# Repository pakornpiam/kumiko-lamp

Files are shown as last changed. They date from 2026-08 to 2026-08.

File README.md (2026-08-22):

# Kumiko Lamp — parametric, print-ready STL set

A parametric lantern for an E27 or E14 LED bulb, available in two styles. **Classic** is
the original square four-panel lamp; **Modern** is a two-part cylindrical lamp with a
threaded patterned shade. Classic remains the default, and its geometry and stock STLs are
unchanged.

The Classic parts print with **no supports** and assemble with sliding
mortise-and-groove joints — no glue and, as it ships, no fasteners of any kind. Four M3
screws are an option, not a requirement; see *Screwing the Classic cap down*. The stock
Classic is **190 × 190 × 236 mm** on its four legs. The stock Modern pairs a
**Ø100 shade and Ø100 base** at 298 mm assembled height. Both are designed for the
256 mm bed of the A1 / P1S / X1C.

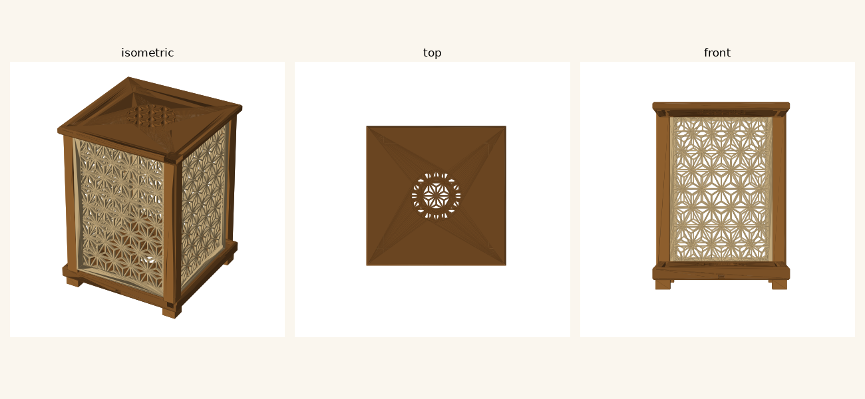
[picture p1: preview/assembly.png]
assembled Classic lamp


## Two ways to build it

**[`web/index.html`](web/index.html) — the configurator.** Open it in a browser, choose
**Classic** or **Modern** under *Lantern*, adjust the dimensions, pattern, joints and
lamp-holder sizing, turn the lamp in 3D, and download the STLs individually or as a zip.
Each style remembers its own settings while you switch between them. No install, no
network, one self-contained file. It re-solves the joinery live and refuses to export a
lamp that will not go together. The new controls and messages are available in both
English and Thai.

**`kumiko_lamp.py` — the generator.** Same selected style, same numbers, built with real
CSG so every part is a strictly manifold shell. Use this if your slicer is fussy, or for
the pre-generated set in `stl/`.

The two agree: for identical settings the structural parts, adapter ring and downloaded
Modern shade come out of the browser watertight and closely volume-matched to the Python
parts. Classic's live-built lattices use a lighter representation — see
[Manifold-ness](#manifold-ness) below.

## Lantern styles

**Classic** is the existing square lamp: four interchangeable panels slide between four
posts, with separate feet, a grooved base and a removable top cap. It supports all thirteen
offered patterns, optional diffusers, two-piece posts, cap screws, finials and reusable
snap locks.

**Modern** is a hollow cylindrical base and a removable cylindrical shade. The reference
preset uses a 100 mm shade diameter, a 100 mm base diameter, a 218 mm shade and a 90 mm
base. In the configurator, **Shade diameter** and **Base diameter** begin linked: moving
the shade-diameter control moves both until you edit Base diameter directly. That first
base edit unlinks them, allowing a broader body while later shade changes keep
the chosen base size. Set Base diameter equal to Shade diameter to relink them; this link
state is remembered when you switch between Classic and Modern. The shade overlaps the
base's threaded neck by 10 mm, producing the 298 mm assembled height. Its upper and lower
rings are each 10 mm high, with the selected Kumiko lattice wrapped continuously around the
cylinder between them. The base carries the male thread and the shade's lower ring carries
the matching female thread. The threaded neck follows the shade diameter; the base body
uses its independently selected diameter. Immediately below the neck, the body contracts
through a 45-degree transition; after the base is inverted for printing, that transition
expands without a horizontal cantilever.

Modern supports the thirteen Kumiko patterns only. The three Lai Thai compositions are
panel-sized artwork and cannot be wrapped periodically, so Modern rejects them instead of
substituting another design. For softer light, set **Diffuser thickness** above zero to
generate a removable closed-top cup, or leave it at zero and add a paper or vellum
liner.

Modern **Seigaiha** is the exception to the normal swept-slat construction. It preserves
the four signed contours from `reference/seigaiha-blue.svg` as a filled 2 × grid by
1 × grid repeat: coloured regions print and white regions remain light openings. At the
reference 1.6 mm material setting it matches the source; Material width offsets that
region thinner or thicker. A fit guard rejects any rounded opening whose estimated roof
bridge exceeds 9 mm, and the repeat-boundary tips are normalized so every row welds.
Classic Seigaiha remains the original three-arc line pattern.

**Sakura V2** is also filled source artwork. Its repeat is extracted directly from
`reference/vectorstock_20834246.svg`: all 79 signed contours preserve the interlocking
blossoms, their openings, and the varying member widths. Pattern pitch scales the complete
repeat; Material width is intentionally ignored for this motif because a uniform offset
would alter the artwork and disconnect its finest joints.

---

## Print list

### Classic (default)

| STL | Qty | Size (mm) | Orientation on the plate |
|---|---|---|---|
| `panel_asanoha.stl` | **4** | 155.7 × 210 × 4 | Flat, **lattice face down**. As exported — drop it on the plate. |
| `post.stl` | **4** | 18 × 18 × 210 | Standing upright, as exported. Use a brim. |
| `base.stl` | **1** | 190 × 190 × 16 | Flat, as exported. Underside is dead flat. |
| `top_cap.stl` | **1** | 190 × 190 × 10 | Flat, as exported — **already flipped** into print orientation. |
| `leg.stl` | **4** | 20 × 20 × 20 | Standing on its foot, as exported. Tenon points up. |
| `socket_adapter_ring.stl` | **1** | Ø49.6 × 4 | Flat. See *E27 / E14 holder* below. |
| `diffuser_plate.stl` | 0 or **4** | 155.7 × 210 × 1.2 | Flat, as exported. Only if you want a printed diffuser — see *Classic diffuser* below. |
| `finial.stl` | 0 or **4** | 20 × 20 × 10 | Screw-head finial cap, standing on its head. Skirt points up. Only with the cap screws. |

Swap in `panel_kikkou.stl`, `panel_mitsukude.stl`, `panel_kawari_asanoha.stl`,
`panel_kagome.stl`, `panel_masu.stl`, `panel_masu_tsunagi.stl`, `panel_senbon.stl`,
`panel_goma_gara.stl`,
`panel_bishamon_kikkou.stl`, `panel_seigaiha.stl`, `panel_sakura.stl` or
`panel_sakura_v2.stl` for a different motif — all thirteen Classic panels are dimensionally identical
and interchangeable. Roughly in order of open area: masu and kikkou are
the airiest, asanoha and goma-gara the densest.

### Modern

| STL | Qty | Reference size | Orientation on the plate |
|---|---|---|---|
| `modern_shade_asanoha.stl` | **1** | Ø100 × 218 mm | Upright, as exported. Use a brim if your slicer or material needs it. |
| `diffuser_plate.stl` | 0 or **1** | Ø91.2 × 208 × 1.2 mm wall/lid | **Lid down, as exported.** Optional removable Modern diffuser cup. |
| `modern_base.stl` | **1** | Ø100 × 90 mm nominal | **Inverted, as exported.** The mounting deck starts on the bed and the neck reaches the body through a 45-degree transition. |
| `socket_adapter_ring.stl` | **1** | Ø49.6 × 4 mm | Flat. The same E27/E14 adapter used by Classic. |

Replace `asanoha` in the shade filename with `kikkou`, `mitsukude`, `kawari_asanoha`,
`kagome`, `masu`, `masu_tsunagi`, `senbon`, `goma_gara`, `bishamon_kikkou`, `seigaiha`,
`sakura` or `sakura_v2`. A reference-size `modern_base.stl` and all thirteen
`modern_shade_<pattern>.stl` files are checked into `stl/`; custom sizes are generated or
downloaded on demand. The supplied reference STLs used to establish the proportions are
not copied into the repository.
The configurator's part table, individual filenames, ZIP name and ZIP contents follow the
selected style; a Modern download does not include Classic-only parts. Individual filenames
stay stable at `modern_base.stl`, `modern_shade_<pattern>.stl` and
`socket_adapter_ring.stl`. A linked Ø100 pair downloads as
`kumiko-lamp-modern-100mm-<pattern>.zip`; unequal diameters are explicit in names such as
`kumiko-lamp-modern-shade100mm-base140mm-<pattern>.zip`.

**Seigaiha** (青海波, "blue sea wave") is the odd one among the kumiko: a field of curves
rather than a straight lattice. Classic uses rows of overlapping three-arc fans, each row
offset half a fan from the one below. Modern instead uses the imported filled repeat
described above, with its wave ends joined for one support-free cylindrical shell.

**Sakura** (桜, "cherry blossom") starts with the same equilateral-triangle groundwork
as other straight-slat Kumiko. A three-spoke insert runs from each triangle's centre to
its edge midpoints, turning the repeating openings into geometric petals. It uses the same
adjustable pitch and material width in Classic and Modern, and the Classic cap keeps the
Sakura lattice rather than substituting a fallback grille.

**Sakura V2** is the exact filled repeat supplied in
`reference/vectorstock_20834246.svg`, not a rotation of the straight-slat Sakura pattern.
It preserves the source's interlocking floral silhouette and varying stroke weights in
Classic and around the Modern shade. Its dense contours are unsuitable at cap scale, so
the Classic top vent safely uses the Kikkou grille when Sakura V2 is selected.

**Masu** (枡格子) and **Senbon** (千本格子) are the plain ones: a bare square grid, and
close-set vertical bars crossed by a rail every third bar. Senbon's bars run at a third of
the pattern pitch, so the stock 28 mm gives a 9.3 mm spacing — fine enough to earn the
"thousand sticks" of its name. At 12 and 22 slats they are the two cheapest panels to
print, and Masu is the most open of the thirteen.

## The Lai Thai family is currently disabled

Three Thai compositions — **Kranok Kan Khot**, **Dok Phut Tan** and **Thai Rosette** — are
still in the repo and still build, but are **not offered**: they are absent from the
configurator's pattern picker, from `--pattern`, and from `--all`. Their three
`panel_*.stl` files and preview SVGs remain checked in, and stop being regenerated.

To bring them back, set **both** flags to true and regenerate:

```
kumiko_lamp.py   LAITHAI_ENABLED = True
web/index.html   var LAITHAI_ENABLED = true;
```

They are switched off rather than deleted because Thai Rosette remains a complete imported
region implementation and test case. The same region machinery now also carries Sakura V2.
The descriptions below are kept for that reason.

**Kranok Kan Khot**
(กระหนกก้านขด) is a different kind of thing: not a repeating lattice but **one composition filling the
whole panel** — a diamond medallion of Thai flame work, with a column of nested pointed
lenses on the axis, a spike to the apex, and volutes at the waist throwing flames out along
the diamond's edges. It is bilaterally symmetric, so only the right half is authored and
mirrored. All four panels carry the same artwork.

Two consequences worth knowing. Because there is no tile, `--grid` has no pitch to set for
this pattern and drives curve tessellation instead. And the top cap keeps a kumiko grille
when it is selected: scaled into the 70 mm vent the composition is just a shrunken copy of
the panel, ~19k triangles in a hole you can barely see into.

**Dok Phut Tan** (ดอกพุดตาน) is a broad, layered flower derived from the peony-like motif
used in early-Rattanakosin Thai ornament. Three scalloped petal tiers grow from a common
heart, while four scrolling stems, paired leaves and forked perimeter braces tie it into
the side, top and bottom rails. Like Kranok,
it is one panel-sized composition rather than a repeating tile, and the cap uses the
Kikkou fallback grille.

**Thai Rosette** is different again: it is not drawn in code at all but **imported**
from `reference/laithai.svg`. Where every other pattern is line work swept into
fixed 1.6 mm slats, this one is a *filled region* — an outer contour plus 13 holes —
so its stroke thickness varies the way the original artwork does. It is fitted to the
panel width undistorted, which leaves a plain band top and bottom, and a thin border
with four diagonal ties and four centre spokes holds it together: on its own the
artwork is two loose pieces and neither reaches the frame.

To change it, edit the SVG and re-run `python tools/svg2pattern.py reference/laithai.svg`,
then paste the table into both implementations — the browser core has no file access,
so the contours have to be baked in.

`post_lower.stl` + `post_upper.stl` are an **optional** two-piece post joined by an 8 mm
pin (117 mm and 105 mm tall). Use them only if you would rather not print a 210 mm tall
slender tower, or you are on a 180 mm-Z machine. Print 4 of each *instead of* `post.stl`.

`assembly_preview.stl` is **not for printing** — a generator run writes the selected style
with its print parts placed upright for checking fit in a viewer. The checked-in stock
preview remains Classic; generate Modern into a separate `--out` directory when you want
its preview.

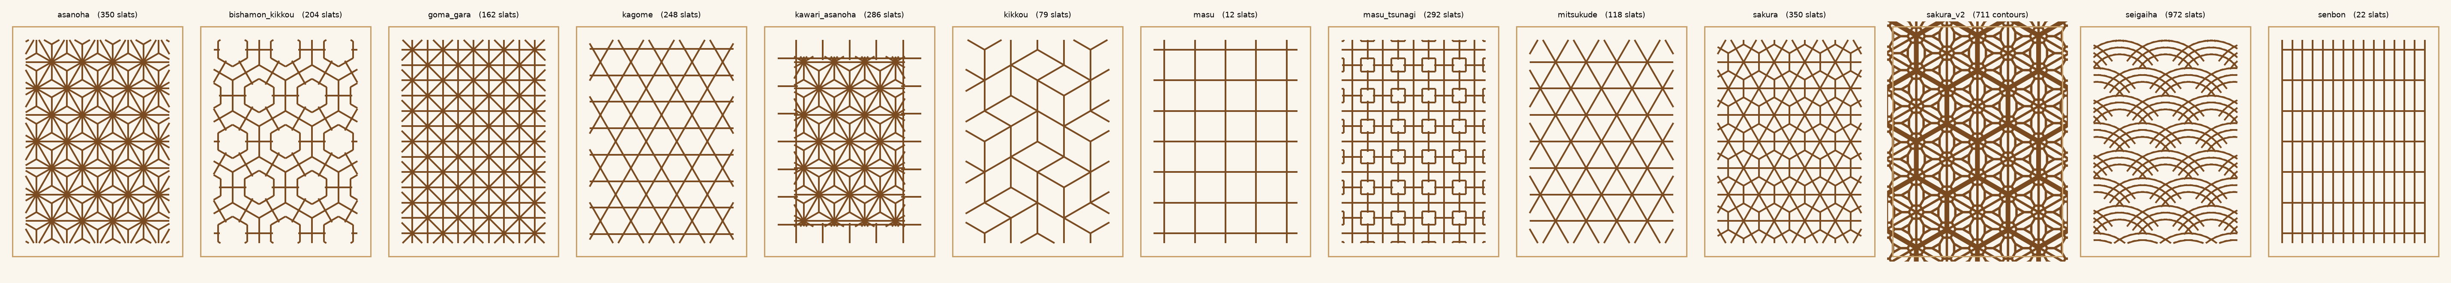
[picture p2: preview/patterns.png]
patterns


## Slicer settings (Bambu Studio)

These are a safe starting point for either style; keep the exported orientations listed
above.

| | |
|---|---|
| Nozzle / layer | 0.4 mm / 0.2 mm — use 0.16 mm on the panels for a crisper lattice |
| Wall loops | **4** — slats are 1.6 mm wide, exactly 4 × 0.4, so they come out fully solid with no infill inside them |
| Infill | 15 % gyroid (only solid frames, posts, bases and the Classic cap ever see it) |
| Supports | **Off** for every part |
| Brim | 5 mm on the posts and panels; optional elsewhere |

Rough Classic filament: one full set is 1323 cm³ of solid volume (1641 g if it were
100 % dense).
The panels and posts are effectively solid; the base and cap are slabs that infill
hollows out considerably. At 15 % infill expect very roughly **700–800 g** — your
slicer's estimate is the one to trust.

## Assembly

### Classic

1. Press the four **legs** into the blind sockets in the underside of the **base**.
2. Drop the four **posts** into the corner sockets on top of the base.
3. Slide each **panel** down between two posts — the grooves in the posts catch its
   side edges, and its bottom edge lands in the groove in the base. Lattice faces out.
4. Fit the **top cap** over the four post tops and the four panel top edges.

It is a friction fit throughout, so the cap lifts off to change the bulb. Fit the optional
cap screws and it does not: four finials come off and four screws come out first. Joint
clearances are 0.4 mm on the grooves, 0.3 mm on panel width and 0.35 mm on the leg
tenons. If your printer runs tight and the panels bind, raise `slot_clear` and reprint
the posts — that is the one part you would need to redo.

### Modern

1. Fit the selected E27/E14 holder and `socket_adapter_ring.stl` to the mounting deck,
   route its cord through the bottom outlet, and complete the wiring before fitting the
   shade.
2. Turn `modern_base.stl` upright after printing; it is exported upside-down only to keep
   the mounting deck and male thread support-free.
3. Add an optional paper liner inside the shade, keeping it clear of the bulb and vents.
4. Lower the shade over the base neck and screw it down through the full 10 mm engagement.
   Stop when the full engagement is reached; do not force or overtighten the printed thread.

Unscrew the shade to change the bulb. The thread uses a 2 mm pitch, 0.8 mm radial depth and
45° printable flanks. Its **radial** clearance slider spans 0.10 to 0.80 mm; the default
0.30 mm is a starting point, not a universal fit:

```bash
python3 kumiko_lamp.py --style modern --thread-clearance 0.20  # tighter
python3 kumiko_lamp.py --style modern --thread-clearance 0.30  # default
python3 kumiko_lamp.py --style modern --thread-clearance 0.60  # looser
```

Start at 0.30 mm, then tune for the material, layer height and dimensional accuracy of your
printer. The generator rejects settings that leave unsafe thread walls or mounting-deck
thickness. A wider independent base does not change the thread fit: its neck still matches
the shade, while the lower body and its support-free 45° transition expand to the selected
base diameter. Check that diameter against both printer-bed axes.

## Classic legs

The legs are separate parts rather than moulded onto the base, and that is deliberate:
hung off the underside they would turn the whole 190 mm slab into an unsupported ceiling,
and every part here prints without supports. A 10 mm square tenon plugs into a blind
socket under each corner post, so the load runs straight down post → base → leg. Square
rather than a round pin, so a leg cannot rotate out of line with the base edges.

They also lift the base 12 mm off the table, which gives the cord somewhere to go.

### Reusable snap locks

The feet are a clearance fit by default. Add a light reusable snap detent with:

```bash
python3 kumiko_lamp.py --snap-lock       # recommended 0.2 mm engagement
python3 kumiko_lamp.py --snap-lock 0.1   # lighter fit
python3 kumiko_lamp.py --snap-lock 0     # off (the default)
```

The same setting applies to the four feet and the four screw-head finial caps, so a
screwed lamp has all eight matching corner pieces retained. Two small tabs flex into
matching hidden recesses; the feet have a hollow tenon and the finials flex around their
screw cavity. Start at 0.2 mm and tune the **Snap engagement** slider for your printer and
material. PETG is preferred for repeated removal; PLA snaps are more brittle. No snap fit
has been test-printed yet.

## Screwing the Classic cap down

The cap is a friction fit and needs nothing else. If you would rather it could not be
lifted off — a lamp that travels, or one somewhere a cat can reach — each post top can
take a **heat-set threaded insert**, with an M3 screw down through the cap into it and a
finial over each screw to hide the head. The finials echo the four legs: four feet below,
four caps above.

```bash
python3 kumiko_lamp.py --post-insert 4.0    # M3, the working value
python3 kumiko_lamp.py --post-insert 0      # none (the default)
```

In the configurator it is the **Insert hole** slider under *Cap screws*; `0` means none.

**You will need:** 4 × M3 heat-set insert, OD 4.6 × 5.7 mm long (the common
Ruthex/CNC-Kitchen size, 4.0 mm pilot) · 4 × M3 × 8 socket cap screw · a 2.5 mm hex key ·
a soldering iron to set the inserts.

Set the inserts into the post tops before assembly, build as usual, then drop a screw
through each corner of the cap and nip it up — **snug, not tight**. The screw pulls the cap
down until the post bottoms out against it, so there is nothing to gain from more torque
and an insert to strip if you keep going. The finials are a light press fit by default or
a removable detent with `--snap-lock`; leave them unglued or you will never get the bulb
out.

**Ø4.0 is the largest hole an 18 mm post will really take.** The panel grooves reach in to
within 3 mm of the post axis, so a 4 mm hole leaves a 1 mm wall — and that wall is where
the insert's melt wants to bulge, into the groove face. `check_fits` refuses anything past
two extrusions of wall, but if you want M4, widen the post to 20 mm first.

## Classic diffuser

The back of every panel is pocketed 0.6 mm deep, and the pocket runs out through the top
edge. Slide a sheet of **shoji paper or vellum** down into it before you fit the cap.
The pocket holds it on the other three sides; the top is hidden inside the cap groove.
Cut the sheet to **139.7 × 202 mm**. Traditionally this is glued — a little PVA around
the edge is plenty, but friction alone works.

Leave it out entirely if you want hard-edged shadows thrown on the wall instead.

### Or print the diffuser

Instead of paper, each groove can take a **clear printed plate** that sits behind the
lattice — same job, no cutting or gluing, and it will not yellow.

```bash
python3 kumiko_lamp.py --diffuser-plate 1.2     # the working thickness
python3 kumiko_lamp.py --diffuser-plate 0       # none (the default)
```

In the configurator it is the **Diffuser plate** slider under *Panel*; `0` means none.
A glazed side renders translucent so you can see the plate through the lattice.

`diffuser_plate.stl` shares the panel's 155.7 × 210 footprint, so the groove holds it on
all four edges. Print it in **clear PETG or PLA** — 1.2 mm is six layers, and it prints
flat with no supports.

The groove widens to take both, `panel + plate + clearance`, and **that is what caps the
plate at 1.6 mm**: the post's two grooves are notches cut 6 mm deep into an 18 mm post,
and once each is half as wide as the 6 mm they leave, the two meet and the post's corner
falls off. `check_fits` refuses anything that reaches it. Nothing else moves — panel
width, the patterns and every other part are identical glazed or not.

You can still use paper as well; the 0.6 mm rebate is untouched.

### Modern diffuser cup

The same `--diffuser-plate 1.2` option creates one cylindrical cup in Modern mode. It rests
on the lower ring, passes through the upper ring, and finishes level with the shade's top
edge. It sits 0.4 mm radially inside the lattice, so it can be removed through the shade
opening. Its upper end is a completely solid flat lid, its lower end remains open, and the
selected 1–4 mm thickness controls both the wall and the lid. The STL is already turned
**lid-down**: print it that way in
**translucent PETG** so the lid starts on the bed and the cup needs no supports. `0` keeps
the original three-part Modern print set and lets you use paper or vellum instead. Because
the lid reduces upward convection, retain the lamp's LED-only, maximum-9 W requirement.

## E27 / E14 holder

Both styles reuse the same holder presets and stable `socket_adapter_ring.stl` filename.
The Classic base has a Ø40 mm through-bore, a Ø50 × 4 mm counterbore around it, and an
enclosed cord tunnel through one side wall. The Modern base puts the same bore and
counterbore in its circular mounting deck and routes the cord through the bottom outlet.

`socket_adapter_ring.stl` seats in the counterbore and is what your holder clamps
against. The E27 preset keeps the original Ø26.5 mm bore; the E14 preset uses a Ø27 mm
bore for the common threaded-sleeve style:

```bash
python3 kumiko_lamp.py --holder e14
```

E14 and E27 name the bulb interface, not the holder's mounting neck, and actual hardware
varies. For example, [one commercial E14 sleeve is specified at Ø27.5 mm](https://produkte.kopp.eu/en/id/212501049/). Measure yours
and override the preset when needed:

```bash
python3 kumiko_lamp.py --holder e14 --socket-neck 27.5
```

It is a 5 g, few-minute print, which is exactly why the fit lives in a separate part
rather than in either base. Select the same holder preset independently in Classic or
Modern; a subsequent manual neck adjustment keeps the selected E27/E14 identity.
The configurator's CLI echo includes `--holder` and also `--socket-neck` when you move the
neck away from that holder's preset.

## Heat — please read

**LED bulb only, 9 W maximum.** A filament or halogen bulb will soften and deform this
lamp. PLA starts to go at around 60 °C.

Ventilation is built in. Classic has 1640 mm² of open area through the cap grille and a
16-slot ring in the base under the bulb; Modern adapts that vent layout to its circular
mounting deck and vents through the open lattice above. Both are sized for a cool-running
LED and nothing more.

I would **print either base, the Classic top cap and the Modern shade in PETG** — they are
the parts nearest the bulb, and PETG holds up to roughly 80 °C. PLA is fine for the Classic
panels and posts. All-PETG is fine too.

Mains wiring is your responsibility. If you are not confident terminating a lamp holder,
use a ready-made corded E27 or E14 socket rather than making one up.

## Customising

Every dimension lives in the `Params` dataclass at the top of `kumiko_lamp.py`. The ones
worth reaching for are on the command line:

```bash
python3 kumiko_lamp.py --all                    # Classic: all 13 offered patterns + both post styles
python3 kumiko_lamp.py --style classic          # explicit form of the unchanged default
python3 kumiko_lamp.py --pattern kikkou         # one Classic pattern's part set
python3 kumiko_lamp.py --grid 20                # finer lattice
python3 kumiko_lamp.py --size 150 --height 170  # smaller lamp (fits an A1 mini)
python3 kumiko_lamp.py --slat 2.0               # chunkier slats (keep it a multiple of 0.4)
python3 kumiko_lamp.py --panel-thickness 5      # thicker Classic panels
python3 kumiko_lamp.py --edge-chamfer 0         # square off the base and cap edges
python3 kumiko_lamp.py --diffuser-plate 1.2     # printed diffuser behind each lattice

python3 kumiko_lamp.py --style modern           # Ø100 × 218 shade + 90 mm base
python3 kumiko_lamp.py --style modern --all     # 13 shades + base/ring + assembly preview
python3 kumiko_lamp.py --style modern --size 120 --height 240
python3 kumiko_lamp.py --style modern --modern-base-diameter 140  # wider body, Ø100 shade
python3 kumiko_lamp.py --style modern --panel-thickness 5  # deeper radial lattice
python3 kumiko_lamp.py --style modern --modern-base-height 100
python3 kumiko_lamp.py --style modern --thread-clearance 0.35
python3 kumiko_lamp.py --style modern --holder e14
```

For Modern, `--size` is the **shade** diameter and `--height` is the shade height.
The base diameter follows `--size` when `--modern-base-diameter` is omitted; supplying the
new flag makes the body independent while the threaded neck remains matched to the shade.
`--panel-thickness` controls Classic panel thickness or Modern radial lattice depth; its
default is 4 mm in either style. `--grid` and `--slat` keep their pattern-pitch and
slat-width meanings. `--style` defaults to `classic`, so existing commands and generated
Classic STLs remain unchanged.

The Classic base and cap carry a 2 mm 45° chamfer on all four perimeter edges. It is
capped at the cord tunnel floor (2 mm by default — raise `cable_floor` for a deeper bevel)
and, at 4.8 mm, by the wall left around the post sockets; `check_fits` refuses anything
past either.

Adding a pattern means writing one `f(w, h, s) -> [segments]` function and registering it
in `PATTERNS`. Two rules, both learned the hard way:

- Periodic patterns must **overshoot** the opening they are given; the caller clips.
- Anything that lands on another slat must **overlap** it, never merely touch. Two slats
  that abut along a single tangent edge union into geometry that does not survive the
  float32 STL round-trip, and the part comes back with unpaired edges.

```bash
pip install -r requirements.txt
python3 kumiko_lamp.py --all
python3 render_preview.py     # optional, needs matplotlib
```

On Windows the interpreter is normally `python`, not `python3` — substitute it throughout.

## Manifold-ness

The browser has no CSG engine, so `web/index.html` builds geometry a different way — a
winding-rule slab decomposition, with T-junctions welded afterwards. The result:

| Part | From the browser |
|---|---|
| `base`, `post`, `leg`, `socket_adapter_ring`, `modern_base` | Single **watertight** shell, volume matched to the Python part |
| Downloaded `modern_shade_*` | Single **watertight** periodic cell-complex shell, including the female thread |
| `panel_*`, `top_cap` and lightweight line-pattern Modern previews | Closed lattice solids, overlapping where slats cross |

The Modern Seigaiha live preview uses the filled periodic cell shell too, at a coarser
responsive grid; its strict download uses the normal sub-millimetre export grid.

There are **no open edges** in the lightweight lattices — every edge is shared by an even
number of faces. But at their crossings the shared ones sit on four faces rather than two,
so a strict manifold check calls them non-manifold and your slicer may offer to repair
them. Every slicer unions overlapping closed solids correctly, so Classic parts print as
drawn.

That is a deliberate live-preview trade. Decomposing every Classic crossing into a single
shell costs eighteen times the triangles and takes seconds per change — measured, not
guessed — which is no way to drive a slider. Modern downloads instead use a cached periodic
cell-complex boundary: it keeps the preview responsive while producing one face-connected
Float32 STL body. `kumiko_lamp.py` remains the real-CSG path for every part.

One consequence worth knowing: the volume shown for a live lattice preview counts
overlapping slats twice, so it reads a few percent high. The downloaded Modern shade's
strict mesh is checked separately against the Python volume.

## How this was checked

`kumiko_lamp.py` fails loudly rather than writing a bad file. Per run it asserts:

- **Parameters**, before any geometry: panel width actually matches the post groove span,
  groove clearances come out as intended, slat width is a whole multiple of the nozzle,
  the cord tunnel does not break into the groove above it, post sockets do not burst out
  of the side of the Classic base. Modern additionally checks its thread walls, clearance,
  engagement, mounting deck, holder spacing, independently selected shade/base diameters,
  the 45° transition between them and each circular bed footprint. Modern Seigaiha also
  rejects a rounded roof bridge over 9 mm.
- **Every exported part, reloaded from its STL** — not the mesh in memory. Watertight,
  consistent winding, a single connected body, and inside the build volume. The round-trip
  through float32 with no shared-vertex index is exactly where defects show up.
- **Assembled clearance**: the parts are transformed into place and booleaned against each
  other. Any shared volume at all is an error, so a binding joint fails the build.

The configurator is checked the same way, headlessly: its geometry core runs in Node and
is compared against the Python generator's measured volumes (`base` and `leg` match to
0.00%, `post` 0.06%, ring 0.25%) and against its pattern segment counts, slat for slat,
across all offered segment patterns and both imported region patterns. Modern adds wrapped-seam,
thread, volume and placement comparisons across its eleven swept patterns and the filled
Seigaiha and Sakura V2 repeats. The page
itself is then driven in headless Chromium — sliders, pattern switches, bed-fit warnings,
a deliberately unassemblable configuration to confirm it blocks rather than exports,
Classic/Modern state switching, linked-until-edited Modern diameters, English/Thai labels,
equal and unequal-diameter ZIP naming, and a real download whose bytes are loaded back as a
mesh. The core is extracted from the shipped HTML for those tests, so what is verified is
what ships.

What that does **not** cover is a test print — I have not run one. Shrinkage and your
printer's dimensional accuracy are the remaining unknowns, and the joints are where they
would show. For Classic, adjust `slot_clear` / `panel_clear` / `socket_clear`; for Modern,
start with `modern_thread_clear` / `--thread-clearance`. The configurator exposes all four.

## Hosting it

The configurator is one self-contained file, so hosting it is copying that file:

```bash
mkdir -p dist && cp web/index.html dist/
```

That is the entire build. It assembles `dist/` rather than publishing `web/`, which also
carries `extract.js` and the test scripts. This repo deploys to a Cloudflare Worker
with static assets on every push to `main`; `wrangler.toml` points at `dist/`.

The page loads with **no network request but its own document** — no CDN, no webfont, no
external image, and a `data:` URI favicon. Opened from `file://` it previews, validates and
prices the whole lamp; only downloading needs the server.

## Downloads

Preview, validation and the print list are free. **Downloads are built server-side by
`kumiko_lamp.py` and need a subscription.**

That is not a padlock on the browser's own output — it is a different artifact. The
browser's Classic lattices are non-manifold overlapping solids, a deliberate trade so the
sliders stay live (see [Manifold-ness](#manifold-ness)). The download is the real CSG
path: strictly manifold shells, reloaded from the STL and checked before they are sent.
If a configuration builds a part that is not watertight, the server refuses it and says
which part rather than shipping something that will not slice.

Three pieces, all in this repo: `container/` runs the generator, `worker/` owns sign-in
and entitlement, and `web/index.html` is the app. The container is never routed publicly.

## Licence

**Proprietary from commit `5ea4957`** — see [LICENSE](LICENSE).

**Commit `3b8d8d5` and everything before it stays MIT, permanently.** A licence
already granted cannot be withdrawn, so any copy or fork taken at or before that point
keeps full MIT rights forever, for any purpose including commercial — that covers the
browser-side generator in `web/index.html`, all of `kumiko_lamp.py`, and the 36 STLs in
`stl/`. The change binds future versions only.

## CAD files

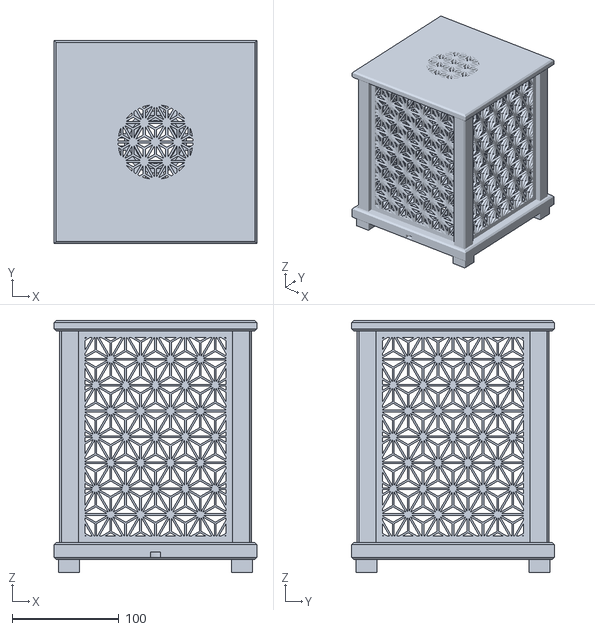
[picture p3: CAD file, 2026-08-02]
stl/assembly_preview.stl
190.0 x 190.0 x 236.0

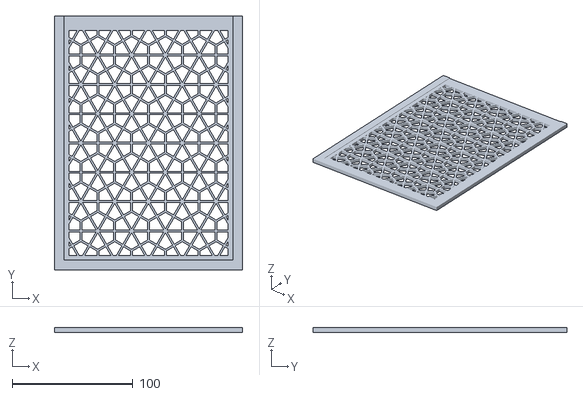
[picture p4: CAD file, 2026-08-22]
stl/panel_sakura.stl
155.7 x 210.0 x 4.00

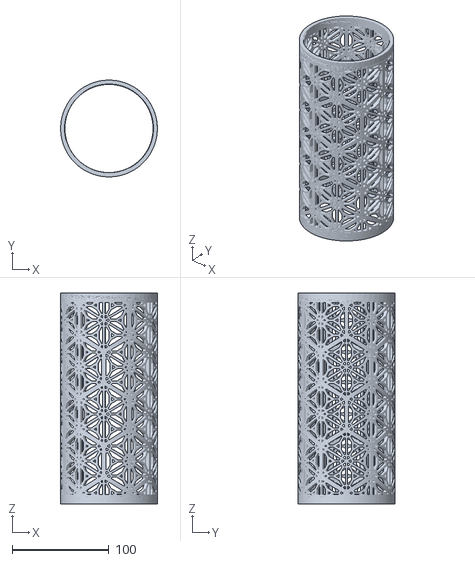
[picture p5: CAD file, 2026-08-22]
stl/modern_shade_sakura_v2.stl
100.0 x 100.0 x 218.0

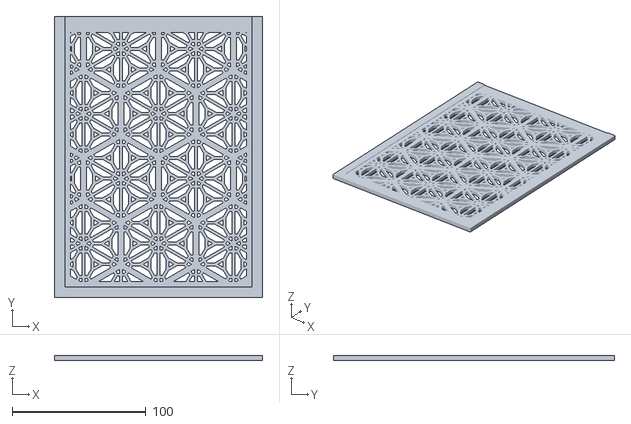
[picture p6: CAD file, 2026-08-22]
stl/panel_sakura_v2.stl
155.7 x 210.0 x 4.00

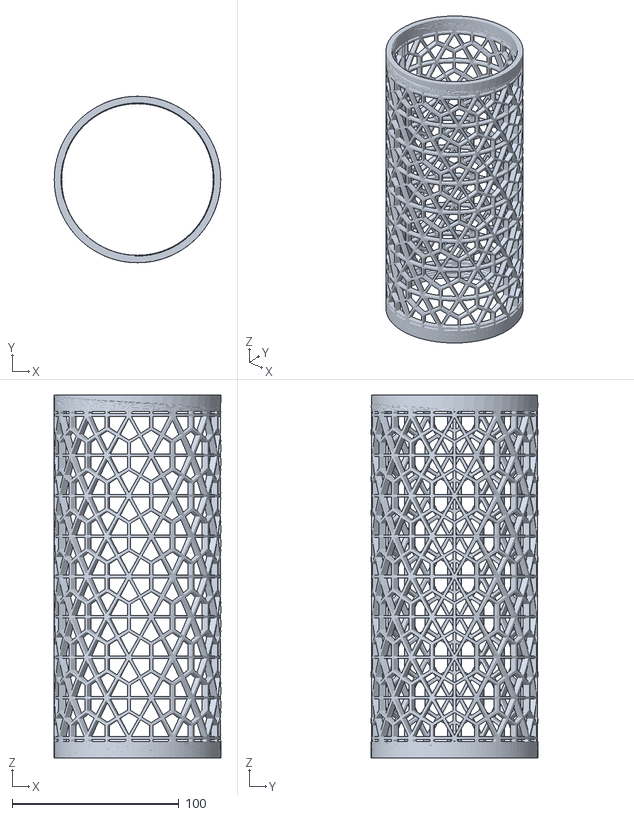
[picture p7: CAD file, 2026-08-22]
stl/modern_shade_sakura.stl
100.0 x 100.0 x 218.0

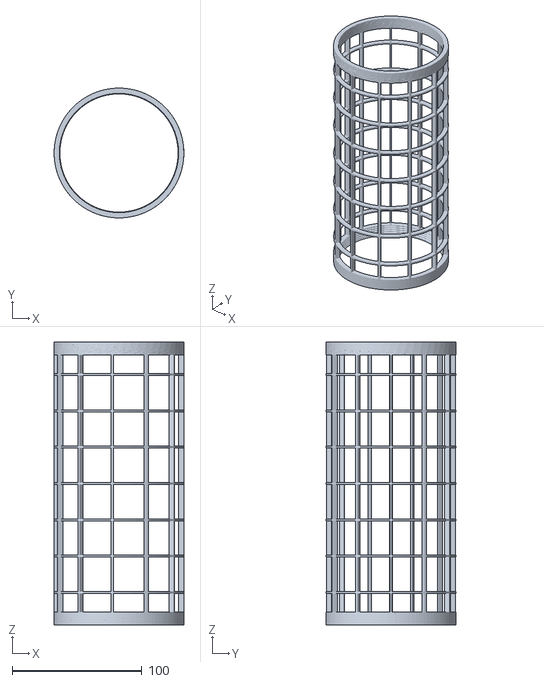
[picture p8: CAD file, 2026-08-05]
stl/modern_shade_masu.stl
100.0 x 100.0 x 218.0

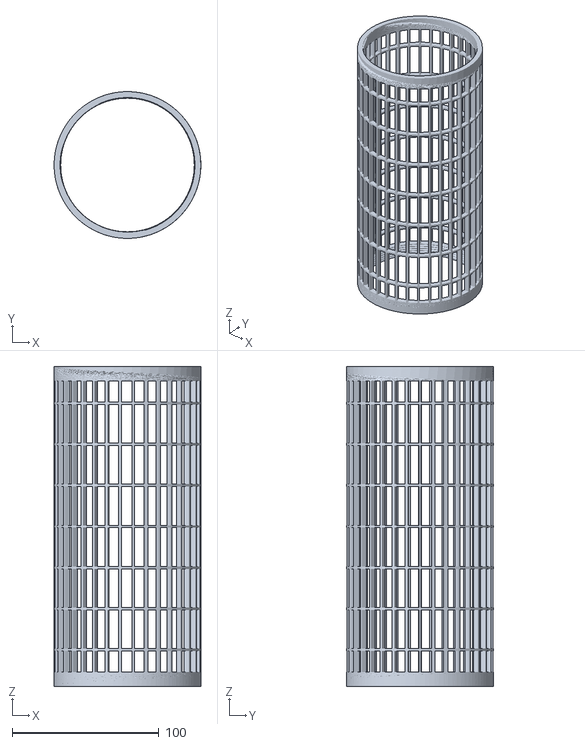
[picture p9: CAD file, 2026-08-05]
stl/modern_shade_senbon.stl
100.0 x 100.0 x 218.0

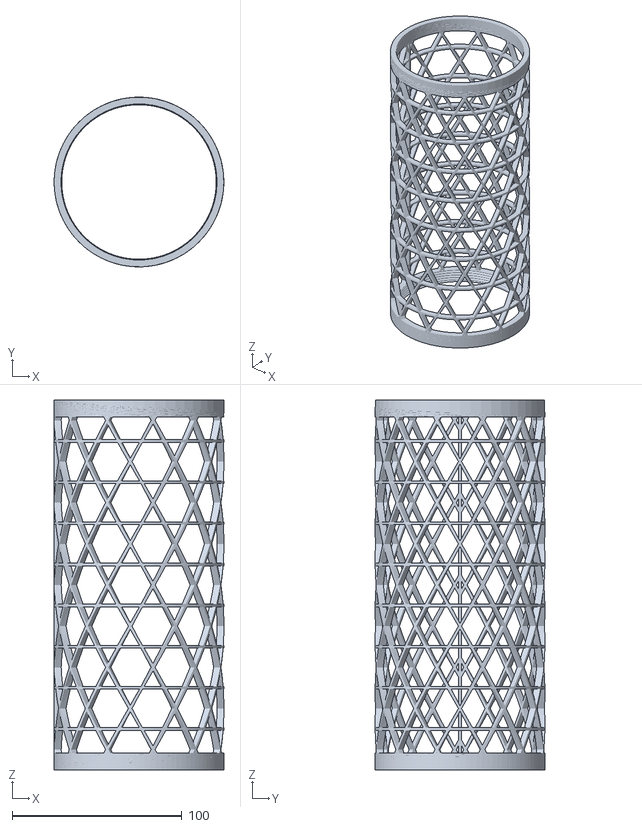
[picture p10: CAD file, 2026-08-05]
stl/modern_shade_kagome.stl
100.0 x 100.0 x 218.0

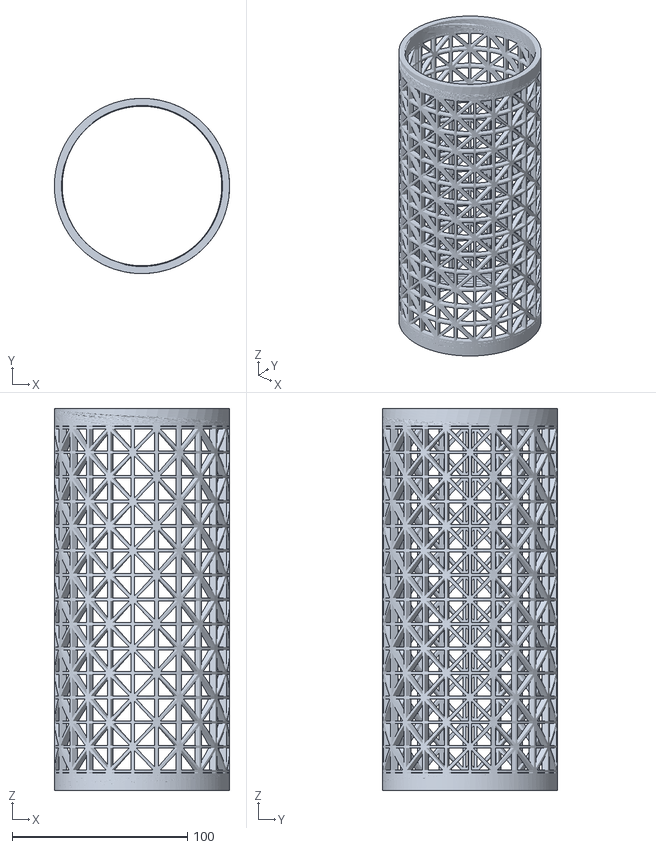
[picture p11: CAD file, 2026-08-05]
stl/modern_shade_goma_gara.stl
100.0 x 100.0 x 218.0

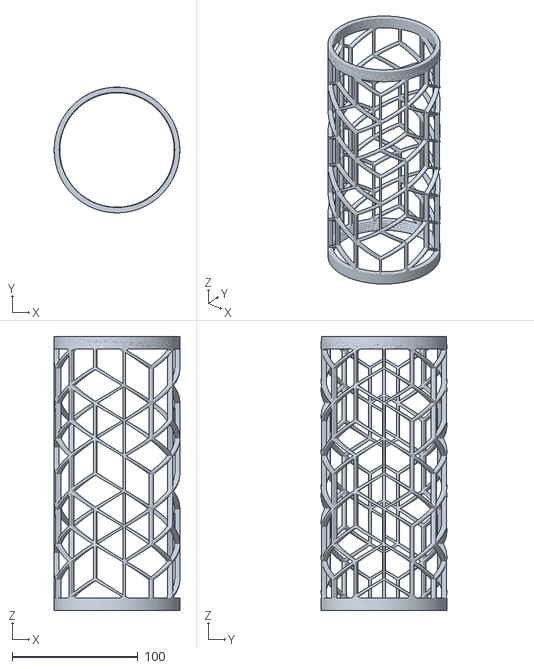
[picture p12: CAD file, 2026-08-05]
stl/modern_shade_kikkou.stl
100.0 x 100.0 x 218.0

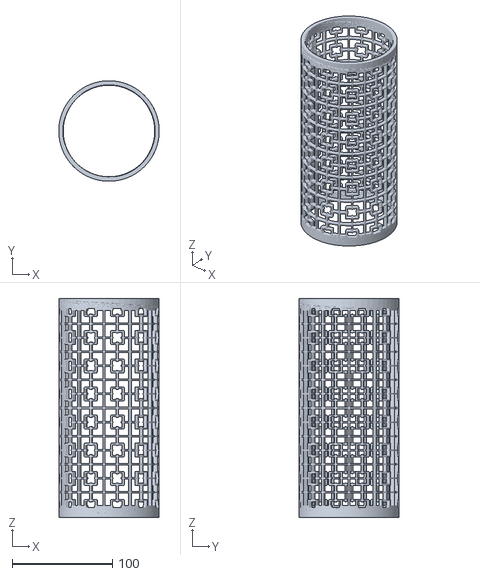
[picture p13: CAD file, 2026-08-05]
stl/modern_shade_masu_tsunagi.stl
100.0 x 100.0 x 218.0

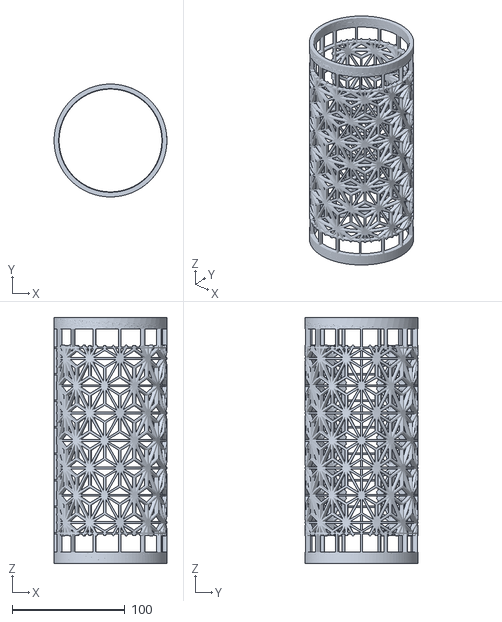
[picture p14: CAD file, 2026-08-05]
stl/modern_shade_kawari_asanoha.stl
100.0 x 100.0 x 218.0

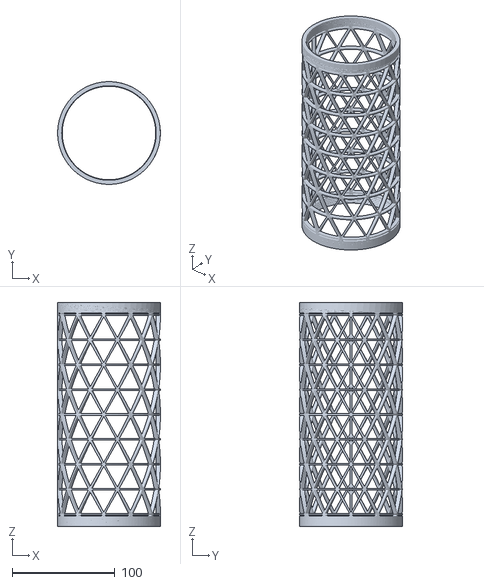
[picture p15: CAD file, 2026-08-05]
stl/modern_shade_mitsukude.stl
100.0 x 100.0 x 218.0

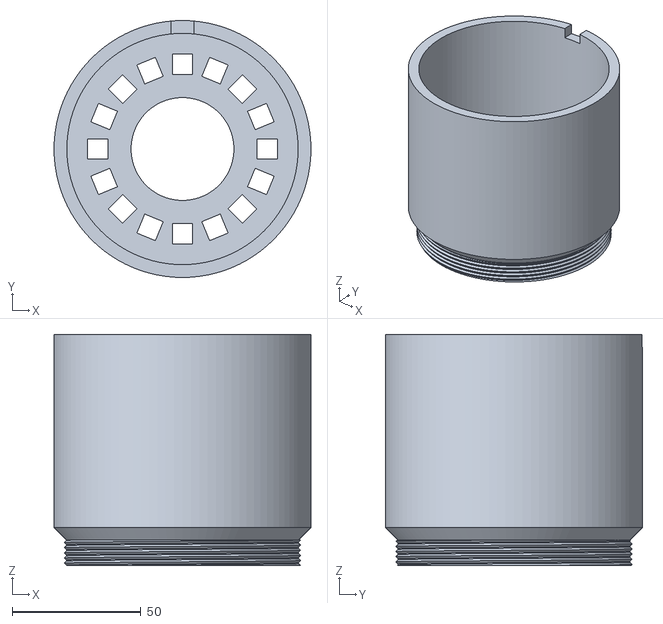
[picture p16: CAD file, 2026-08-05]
stl/modern_base.stl
100.0 x 100.0 x 90.0

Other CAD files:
stl/modern_shade_asanoha.stl
stl/modern_shade_bishamon_kikkou.stl
stl/finial.stl
stl/panel_masu.stl
stl/base.stl
stl/diffuser_plate.stl
stl/leg.stl
stl/panel_asanoha.stl
stl/panel_bishamon_kikkou.stl
stl/panel_dok_phut_tan.stl
stl/panel_goma_gara.stl
stl/panel_kagome.stl
stl/panel_kawari_asanoha.stl
stl/panel_kikkou.stl
stl/panel_kranok_kan_khot.stl
stl/panel_masu_tsunagi.stl
stl/panel_mitsukude.stl
stl/panel_seigaiha.stl
stl/panel_senbon.stl
stl/panel_thai_rosette.stl
stl/post.stl
stl/post_lower.stl
stl/post_upper.stl
stl/socket_adapter_ring.stl
stl/top_cap.stl

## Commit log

2026-07-28 Add parametric kumiko lamp with print-ready STL set
    A square four-panel kumiko lantern for an E27 LED bulb, 190x190x224 mm,
    sized for the 256 mm bed of the A1/P1S/X1C. Every part prints flat with no
    supports and the lamp assembles with sliding mortise-and-groove joints, so
    it needs no glue or fasteners.
    kumiko_lamp.py generates the geometry with real CSG (trimesh + manifold3d)
    rather than overlapping shells. Four kumiko patterns are implemented behind
    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
    [assembly_preview.stl, base.stl, panel_asanoha.stl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]
2026-07-28 Add browser configurator for the kumiko lamp
    web/index.html is a self-contained page - no build step, no network - that
    drives the same lamp as kumiko_lamp.py. Sliders cover size, pattern, panel
    and frame dimensions, the three joint clearances and the E27 sizing; the
    lamp re-solves live in a WebGL view lit from inside, and parts download as
    individual STLs or a zip of the set.
    The Python check_fits() guard is ported and blocks export rather than
    emitting a lamp that cannot be assembled - which matters now that joint
    clearances are user-editable.
    The browser has no CSG engine, so geometry is built by a winding-rule slab
    decomposition with T-junctions welded afterwards, rather than by boolea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
2026-07-30 feat: add kagome, masu-tsunagi, goma-gara and bishamon-kikkou patterns
    The existing four are all triangle- or hex-derived; these add the square
    and diamond families and give a light/heavy pair within the hex family.
    kagome is the medial lattice of the triangular grid, so it reuses the
    existing triangle helper. masu-tsunagi bridges its inner squares to the
    grid at four midpoints, which is what keeps the cap grille in one piece
    once the field is clipped to a disc. bishamon-kikkou runs its spokes
    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
    [panel_bishamon_kikkou.stl, panel_goma_gara.stl, panel_kagome.stl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]
2026-07-30 feat: add four press-fit legs to the base
    Separate parts rather than moulded onto the base: hung off the underside
    they would turn the whole 190 mm slab into an unsupported ceiling, and
    every part here prints without supports. A 10 mm square tenon plugs into
    a blind socket under each corner post, so the load runs post -> base ->
    leg. Square rather than a round pin so a leg cannot rotate out of line
    with the base edges. Assembled height goes 224 -> 236 mm.
    Also rebuilds the JS buildBase layer stack from sorted breakpoints rather
    than a fixed list. Which feature sits above which depends on the sliders,
    and the old hardcoded order would extrude to silent garbage once the leg
    socket depth joine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
    [assembly_preview.stl, base.stl, leg.stl]
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2026-07-31 feat: split the pattern picker into family tabs
    Nine patterns in one grid had become a wall of buttons, and the two
    traditions do not belong in the same list. A tab strip above the grid
    filters by PATTERN_FAMILY; tabs and buttons are both generated from the
    core's metadata, so another family needs no UI code. The active tab
    initialises from the current pattern.
    Renames the group from "Kumiko" to "Pattern" since it no longer holds
    only kumiko, and makes the print-list label follow the family so the
    vine is not listed as a "Kumiko panel".
2026-07-31 docs: document the pattern families and the real cost model
    Records what benchmarking actually showed: panel and cap-grille slats are
    independent prisms, not slabs through extrudeStack, so the 410-slat
    curved kranok panel builds in ~37 ms. extrudeStack's cost is driven by
    distinct vertex Y values and only ever sees the frame, base and cap
    plate. I had assumed the opposite and budgeted the motif against the
    wrong path.
    Also notes the two traps the last two patterns hit: aim spokes at edge
    midpoints rather than vertices, and bound spirals by their outer radius.
2026-07-31 feat: let the cap wear the kranok grille
    The fallback was added on my assumption that a curved motif would
    fragment when the cap clips its field to a disc. Measured, it doesn't:
    kranok's full-width stems come out of the clip as chords still tied to
    the rim, single-body and watertight across the whole grid and cap-vent
    slider range. So the cap follows the panel selection as it does for
    every other pattern.
    Keeps the mechanism as the backstop for a future curved motif that does
    NOT survive the clip — CAP_UNSAFE is now an explicit list, currently
    empty — and the core test flips the flag to prove the fallback path
    still works rather than leaving it untested.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
2026-07-31 feat: redraw the kranok as a single panel composition
    The reference drawing is one composition filling the panel, not a
    repeating tile: flame leaves growing inward from a border around a single
    diagonal stem, each with a volute coiled in its base. Replaces the tiled
    vine with a hand-authored layout in fractions of the opening, plus a
    _leaf primitive (convex outer sweep, concave inner return, hooked tip)
    that mirrors via a `bow` flag.
    Connectivity had to be designed rather than inherited. A tile got frame
    contact and inter-unit contact for free; a composition gets neither, and
    the first build came back as two bodies because a volute was sitting
    inside its leaf touching nothing. Every coil is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
    [panel_kranok_kan_khot.stl]
2026-07-31 feat: redraw the Lai Thai panel as a diamond kranok medallion
    Replaces the rejected free composition with the second reference: a
    diamond medallion of Thai flame work. Bilaterally symmetric, so only the
    right half is authored and mirrored about the axis, which is what makes
    it tractable where the freehand layout was not.
    Structure: a diamond whose four strokes overshoot their vertices, a
    column of nested pointed lenses on the axis with a spike to the apex and
    a lobe to the base, and per side a volute flame at the waist sweeping up
    and out plus flames running along the upper and lower edges.
    Adds a _mandorla primitive for the nested lenses -- _leaf cannot express
    one, since a leaf has a rou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
    [panel_kranok_kan_khot.stl]
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2026-07-31 feat: strengthen Dok Phut Tan frame anchors
    [panel_dok_phut_tan.stl]
2026-07-31 feat: import Thai Rosette from SVG as a region pattern
    Three hand-authored attempts at a Thai motif were rejected, so this takes
    the artwork straight from the user's vector file instead of interpreting
    it. reference/laithai.svg is the source; tools/svg2pattern.py flattens it
    to contours.
    Adds a second kind of pattern. PATTERNS holds segment patterns swept into
    fixed 1.6 mm slats; PATTERN_REGIONS holds filled regions -- an outer
    contour plus holes -- extruded directly. Regions exist because imported
    artwork has varying stroke thickness, which fixed-width slats cannot
    express, and that is why the earlier attempts could never look right.
    Python extrudes via manifold3d.CrossSection (shapely is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
    [panel_thai_rosette.stl]
2026-08-02 feat: chamfer the base and cap perimeter edges
    A true 45 deg bevel on all four horizontal perimeter edges of the base and
    the top cap, driven by a new `edge_chamfer` / `edgeChamfer` parameter.
    The cap already claimed to have one, but the code subtracted a rectangular
    annulus constant in z -- a square step, not a bevel, and printed top-face-down
    it was a 2 mm horizontal overhang rather than the "printable 45 deg flare" its
    comment promised. The browser dropped the feature entirely because a tapered
    wall is not a prism. Both are fixed here, so the two builds agree again.
    Python subtracts four square prisms turned 45 deg about their own edge
    direction, mirroring the trick build_post already u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
    [assembly_preview.stl, base.stl, top_cap.stl]
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2026-08-02 docs: chamfer, clear sides, and the tapered-wall constraints
    README gains a Clear sides section and the two new CLI flags, plus the chamfer
    and its two limits. Print list gains clear_plate.stl at qty 0-4.
    CLAUDE.md gains the constraints a future change has to respect rather than
    rediscover: what extrudeStack now guarantees about a tapered layer and why only
    the outer loop may move, that derive() coerces every parameter numerically so a
    non-numeric one needs its own escape hatch, that GROUPS can only express a
    range slider, and that per-side variation is cheap only while the plate shares
    the panel envelope.
    Also fixes a stale note: page.test.js has not hardcoded /opt/pw-browsers for a
    while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
2026-08-02 fix: regenerate assembly_preview.stl from the stock configuration
    The clear-plate commit picked up the preview left behind by a
    --clear-sides all run, so the checked-in assembly showed four glass
    plates instead of the default asanoha lamp. Regenerated with --all.
    [assembly_preview.stl]
2026-08-02 fix: guard the panel groove against cutting the post corner
    The post carries its two grooves as notches, each reaching in to
    post/2 - groove_d. Once a notch is half as wide as the material that
    depth leaves, the two meet across the diagonal and the post's outer
    corner comes away as a separate body.
    That is reachable from the sliders today: panelT maxes at 7 and
    slotClear at 1.0, giving slotW 8.0 against a 6.0 ceiling. Verified --
    build_post returns body_count 2 at 8.0, and at exactly 6.0 as well, so
    the test is >= and not >. check_fits said OK for both.
    Python caught the symptom downstream as check_part's bodies != 1
    without saying why; the browser has no body-count check at all and
    would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
2026-08-02 feat!: replace the per-side clear plate with a diffuser plate behind the lattice
    The per-side clear plate REPLACED a side's lattice. It should ADD to it: the
    plate is glazing that sits behind the kumiko, where the paper diffuser sheet
    otherwise goes, with the pattern panel still there.
    So the per-side substitution becomes a global option. The Sides group,
    Params.sides, side0..side3, SIDE_NAMES and --clear-sides all go; a single
    plate_t / plateT takes their place, and the groove widens to hold both:
    slot_w = panel_t + plate_t + slot_clear
    The thickness slider is also the switch -- 0 means no plate, which collapses
    slot_w to the un-glazed width. It defaults to 0, so the stock lamp is
    by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
    [clear_plate.stl, diffuser_plate.stl]
2026-08-02 docs: the diffuser plate replaces the per-side clear plate
    README folds it into the Diffuser section as an alternative to the paper
    sheet, with the post-corner ceiling explained where a reader would hit it.
    CLAUDE.md swaps the per-side paragraph for the constraint that actually
    governs this area -- slot_w < post - 2*groove_d, why it is the ceiling on
    plate_t, and that slot_w moves no other dimension because panel_w comes
    from groove_d rather than from it. Also records the 3 * 0.2 float trap
    and the slider-zero-means-off idiom.
2026-08-03 feat: add the Seigaiha pattern
    Seigaiha (青海波, "blue sea wave") -- rows of overlapping fans, three
    concentric arcs each, alternate rows offset half a fan. The first curved
    pattern in the kumiko family; every other curve in the repo is a Lai Thai
    composition.
    Fan radius is 1.5x the pattern pitch, centres sit a = R apart along a row,
    rows are 0.6 R apart. Adds an _arc / arcPts helper -- the file had a Bezier
    and a log spiral but no plain circular arc -- and moves _stroke / strokePts
    up beside _extend / extend, since a polyline helper is no longer Lai Thai
    specific.
    Two things decided the geometry.
    Connectivity: concentric arcs never touch each other, so nothing within a fan
    ties it tog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
    [panel_seigaiha.stl]
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2026-08-07 feat: disable the Lai Thai pattern family
    Kranok Kan Khot, Dok Phut Tan and Thai Rosette stop being offered: gone from
    the configurator's picker, from --pattern and from --all. Classic drops from
    fourteen patterns to eleven; Modern was already eleven and is untouched.
    They are switched off rather than deleted. thai_rosette is the only region
    pattern, so removing the family would take PATTERN_REGIONS, extrude_region,
    is_region, _write_region_svg and the whole imported-artwork extension point
    with it -- roughly 1,080 source lines and 2.6 MB of artwork and STLs. All of
    that stays and keeps compiling; one flag per implementation is the whole
    switch, and flipping both back to true is the whole r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
2026-08-07 fix: move the pattern picker out of the rail so its sliders stay reachable
    Reported as controls missing from the Lantern and Pattern boxes. Nothing was
    missing: the rail is capped to the viewport and scrolls inside itself, and the
    two pinned groups needed 673px (Classic) / 843px (Modern) against a rail of
    476px at 1280x720 and 524 at 1366x768. Everything past that sat below an
    internal fold whose only cue is a reserved scrollbar, so it read as absent
    rather than as scrolled away. In Modern even 1920x1080 lost Lattice depth.
    The picker was 280px of that -- eleven buttons two-across plus a family tab
    strip -- and the column beside the preview had been sitting empty since the
    viewer went sq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
2026-08-07 fix: give the page a charset, a viewport and a favicon
    The file is a bare fragment -- no doctype, no html/head/body, and until now no
    meta at all -- which is fine from disk and not fine on a public host.
    Without a charset the Thai UI depends entirely on the server sending one.
    Without a viewport a phone lays out at ~980px and zooms out, so the one-column
    layout under 940px and the 420px case never run at all; the responsive CSS was
    already written and tested, it just never got a chance to apply.
    The favicon is a data: URI rather than a file, which keeps the property that
    the page issues no network request whatsoever -- verified by serving it and
    watching the request log, where the only ent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
2026-08-07 fix: configure wrangler.toml for a Worker, not a Pages project
    The first build failed at the deploy step:
    Executing user deploy command: npx wrangler deploy
    [WARNING] It seems that you have run `wrangler deploy` on a Pages project
    [ERROR] Missing entry-point to Worker script or to assets directory
    The build itself was fine -- `mkdir -p dist && cp web/index.html dist/`
    completed. The mismatch is what created the project: the dashboard "import a
    repository" flow makes a Worker with static assets, not a Pages project, which
    is why the build carries a deploy command of its own at all. Checking bears it
    out -- there is no kumiko-lamp Pages project, and a Worker of that name was
    crea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
2026-08-07 fix: tile the settings rail instead of stretching it when it goes full width
    Reported as too much gap in the Lantern and Pattern boxes after the deploy.
    Under 940px the bench collapses to one column and the rail spans the whole
    page. As a flex column that stretched every card to match: an 820px tablet gave
    a 772px card holding a 742px slider, with the label pinned to the far left and
    its value to the far right. That gulf is the gap.
    A maximised desktop window reaches this branch too, which is why it did not
    read as a narrow-window problem -- Windows display scaling divides the CSS
    width, so a 1366 screen at 150% is 911px and a 1920 at 250% is 768. The
    viewport meta added for the deploy als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
2026-08-07 feat!: build downloads on the server behind a subscription
    BREAKING: the browser no longer produces STLs. Export posts the slider set to
    /api/export and the CSG generator builds it, which is the point -- the page's
    own Classic lattices are non-manifold overlapping solids and were never what
    anyone should print. The server refuses anything check_part rejects, so a
    customer cannot be sold a panel that is not watertight.
    The account panel lives under the download button because that is the only
    gated thing on the page: preview, validation and the print list stay free.
    Every string goes through t() and has Thai, including the Stripe and auth
    errors, and the panel is redrawn on a language switch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
2026-08-08 chore: set the subscription price to USD 3/month
    Safe to commit: a price id names a public product, and checkout is created
    server-side with the secret key, so knowing it buys nothing.
    Recorded here rather than in the dashboard because swapping this for a live-mode
    id is the switch that starts taking real money, and this is the only place that
    decision leaves a trace. Stripe rejects a test id paired with a live key rather
    than silently charging, which is the right way for that mistake to fail.
2026-08-12 feat: lift the Classic adapter seat on a socket riser
    Add socket_riser / socketRiser: a chimney grown out of the Classic base that
    carries the adapter counterbore up so the lamp holder hangs hidden inside it
    instead of standing exposed in the lantern. 60 mm clears a typical E27.
    0 disables the whole feature the way plate_t and post_insert_d do -- with the
    riser off, socket_seat_z is exactly base_t, the cutters are unchanged and every
    checked-in artifact regenerates byte-identical.
    The tube's outside follows the counterbore it has to carry (SOCKET_RISER_WALL
    either side, Ø56 at stock) rather than adding a second slider, and check_fits
    guards the four ways it can go wrong: negative, under t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
2026-08-12 feat: add a Panels toggle to the preview
    The lattice is what hides everything inside the lamp -- the holder, the socket
    riser under it, the cord run, the vent ring -- so add a third button beside
    Assembled/Exploded that turns it off. Pressed means shown.
    Preview only: the print list, the ZIP and kumiko_lamp.py are untouched, so
    hiding the panels changes nothing about what prints.
    One predicate covers both styles. assemble() already tags the Classic panels,
    the clear plates behind them and the Modern shade with kind 'panel', so
    uploadScene skips that kind in both of its passes -- filtering only the opaque
    one would leave four sheets of glazing hanging where the panels were.
    The flag is not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
2026-08-12 fix: let the counterbore reach its full 74 mm
    The Counterbore slider runs 26-74 but anything over 57.9 was refused, because
    the ventilation ring was nailed to r29-37 and the pocket wall reaches
    socket_cbore / 2. With a socket riser fitted the ceiling was 51.9. The guards
    were right about the collision; what was wrong is that the app offered a range
    it would not build and gave no control that could resolve it -- base_vent_r0,
    base_vent_r1 and base_vents have never had a slider in either style rail.
    base_vent_r0 becomes the ring's minimum radius rather than its exact one:
    derived vent_r0 / vent_r1 step the ring out to clear holder_outer_r +
    HOLDER_VENT_GAP, carrying the ring's width with them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
2026-08-12 fix: name the cap-screw hardware and draw it
    The Cap screws feature worked -- the slider echoes --post-insert, the cap gains
    its holes and four finials appear -- but the screw itself was invisible in every
    sense. Nothing said what to buy: no thread, no length, no mention of the
    heat-set inserts, no step telling you to screw the cap down, and nothing
    screw-shaped anywhere, since the finial caps sit over the heads. A feature named
    Cap screws left you with four holes and no way to fill them.
    Derive the spec from what was already there: screw_d inverts the pilot hole,
    cap_floor and post_insert_h give the length window, and the longest stock length
    inside it is the recommendation -- M3 x 8 at st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
2026-08-12 feat: make cap screws an Off/M3 choice and draw the four inserts
    The feature was switched by dragging Insert hole off 0 -- the file's usual
    "a slider whose 0 means off" trick -- but almost every other value on that
    slider was a way to get the lamp wrong: 5.6 breaks into the panel groove, 4.4 is
    not a screw anyone sells, and M4 cannot reach full engagement in a 6.5 mm blind
    hole. It is a choice, not a dimension, so the rail now offers Off or M3 through
    the same labelled button pair the E27/E14 row uses, behind a capScrews: flag.
    postInsertD is untouched everywhere else -- Params, DEFAULTS, exportParams,
    --post-insert and every guard -- because --params-json can still hand the API any
    value.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
2026-08-12 feat: add a leg chamfer, breaking the arrises of all eight blocks
    The four feet and the four finials are the same block -- build_cap_finial reads
    P.leg and P.leg_tenon and says so -- and they were the last sharp-cornered
    pieces on the lamp: the post already breaks its outward arris, the base and cap
    break all four perimeter edges.
    leg_chamfer takes a 45 degree break on the four vertical arrises of each, so one
    number details all eight and the two ends of the lamp cannot drift apart. 0
    disables it and both parts keep their exact existing geometry, so every
    Python factors the trick build_post already used on its single arris into
    _arris_chamfer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
2026-08-12 fix: stop the preview freezing on fine-pitch patterns
    Every slider tick rebuilds the model synchronously 40 ms later, so anything slow
    in buildAll is a frozen page -- and buildPanel appended each slat with
    `tris = tris.concat(prismFromLoop(...))`, which allocates a new array and copies
    everything built so far. That is quadratic in the slat count. Measured here:
    400 slats cost 24 ms that way and 2 ms in place, 7000 cost 7.3 s against 10 ms,
    12000 cost 20.6 s against 15 ms.
    A 230 mm seigaiha panel at pitch 12 is about 7000 slats, and it was the freeze:
    buildAll took 5569 ms, of which buildPanel was 4792 ms. It is now 209 ms. In the
    real page, dragging the pitch from 24 to 12 at that size bloc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
2026-08-13 fix: pin modern holder and pack customization cards
2026-08-15 fix: keep the preview interactive when a build fails validation
    draw() was gated on model.parts, but what it paints is the last scene
    uploaded to the GPU -- a different question from whether the current
    slider set builds. checkFits failing returns parts: null, so the guard
    turned every orbit, zoom, view-toggle and resize into a no-op while the
    last valid lamp stayed on screen: the preview read as frozen.
    Reachable from the Panel card alone, which is where it was reported.
    slotW is panelT + plateT + slotClear and must stay under post - 2 *
    grooveD (6.0 at stock), so Panel > Thickness freezes the viewport above
    5.4 mm while the slider runs to 7.
    The scene now carries the height and bulb posi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
2026-08-15 feat: package the configurator as an installable Windows app
    Adds a desktop build: the same web/index.html, served locally, with the
    real export path behind it so Download produces print-ready STLs with no
    internet, no Worker and no subscription.
    Entitlement is the only thing stubbed. tools/dev_export_server.py stands
    in for the Worker's two browser-facing routes and forwards geometry
    untouched to container/server.py, which runs kumiko_lamp.py as a child
    process with check_fits, check_part and the clearance pass intact. A
    lamp this refuses is one the hosted app refuses too, with the same
    wording.
    container/server.py needed the only production change. A frozen build
    has no python.exe and no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
